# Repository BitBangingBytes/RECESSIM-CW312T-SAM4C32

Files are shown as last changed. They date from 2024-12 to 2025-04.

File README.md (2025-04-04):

Target board as seen in [RECESSIM video](https://www.youtube.com/watch?v=IOD5voFTAz8)

Note the UART Bootloader connections were routed to the wrong pins and need to be fixed. You can see the bodge wires in the video.

This does not affect the JTAG attack shown however, or programming the chip via JTAG. It works fine for that.

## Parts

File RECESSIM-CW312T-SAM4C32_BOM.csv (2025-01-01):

Reference | Value | Datasheet | Footprint | Qty | DNP | Digikey
C1,C2,C5 | 0.1uF | ~ | Capacitor_SMD:C_0603_1608Metric | 3 |  | 478-KGM15AR70J104KMCT-ND
C3,C4 | 2.2uF | ~ | Capacitor_SMD:C_0603_1608Metric | 2 |  | 1276-1886-1-ND
C6,C7,C8,C9 | 0.1uF | ~ | Capacitor_SMD:C_0603_1608Metric | 4 | DNP | 478-KGM15AR70J104KMCT-ND
R1,R2,R3,R4 | 10 | ~ | Resistor_SMD:R_0603_1608Metric | 4 |  | RR08Q10DCT-ND
R5,R6 | 100k | ~ | Resistor_SMD:R_0603_1608Metric | 2 |  | RR08P100KDCT-ND
R7 | 100 | ~ | Resistor_SMD:R_0603_1608Metric | 1 |  | RR08P100DCT-ND
U1 | ATSAM4C32C |  | RECESSIM-CW312T-SAM4C32:TQFP-100_14x14mm_P0.5mm_W0.28mm | 1 |  | 150-ATSAM4C32CA-AUT-ND

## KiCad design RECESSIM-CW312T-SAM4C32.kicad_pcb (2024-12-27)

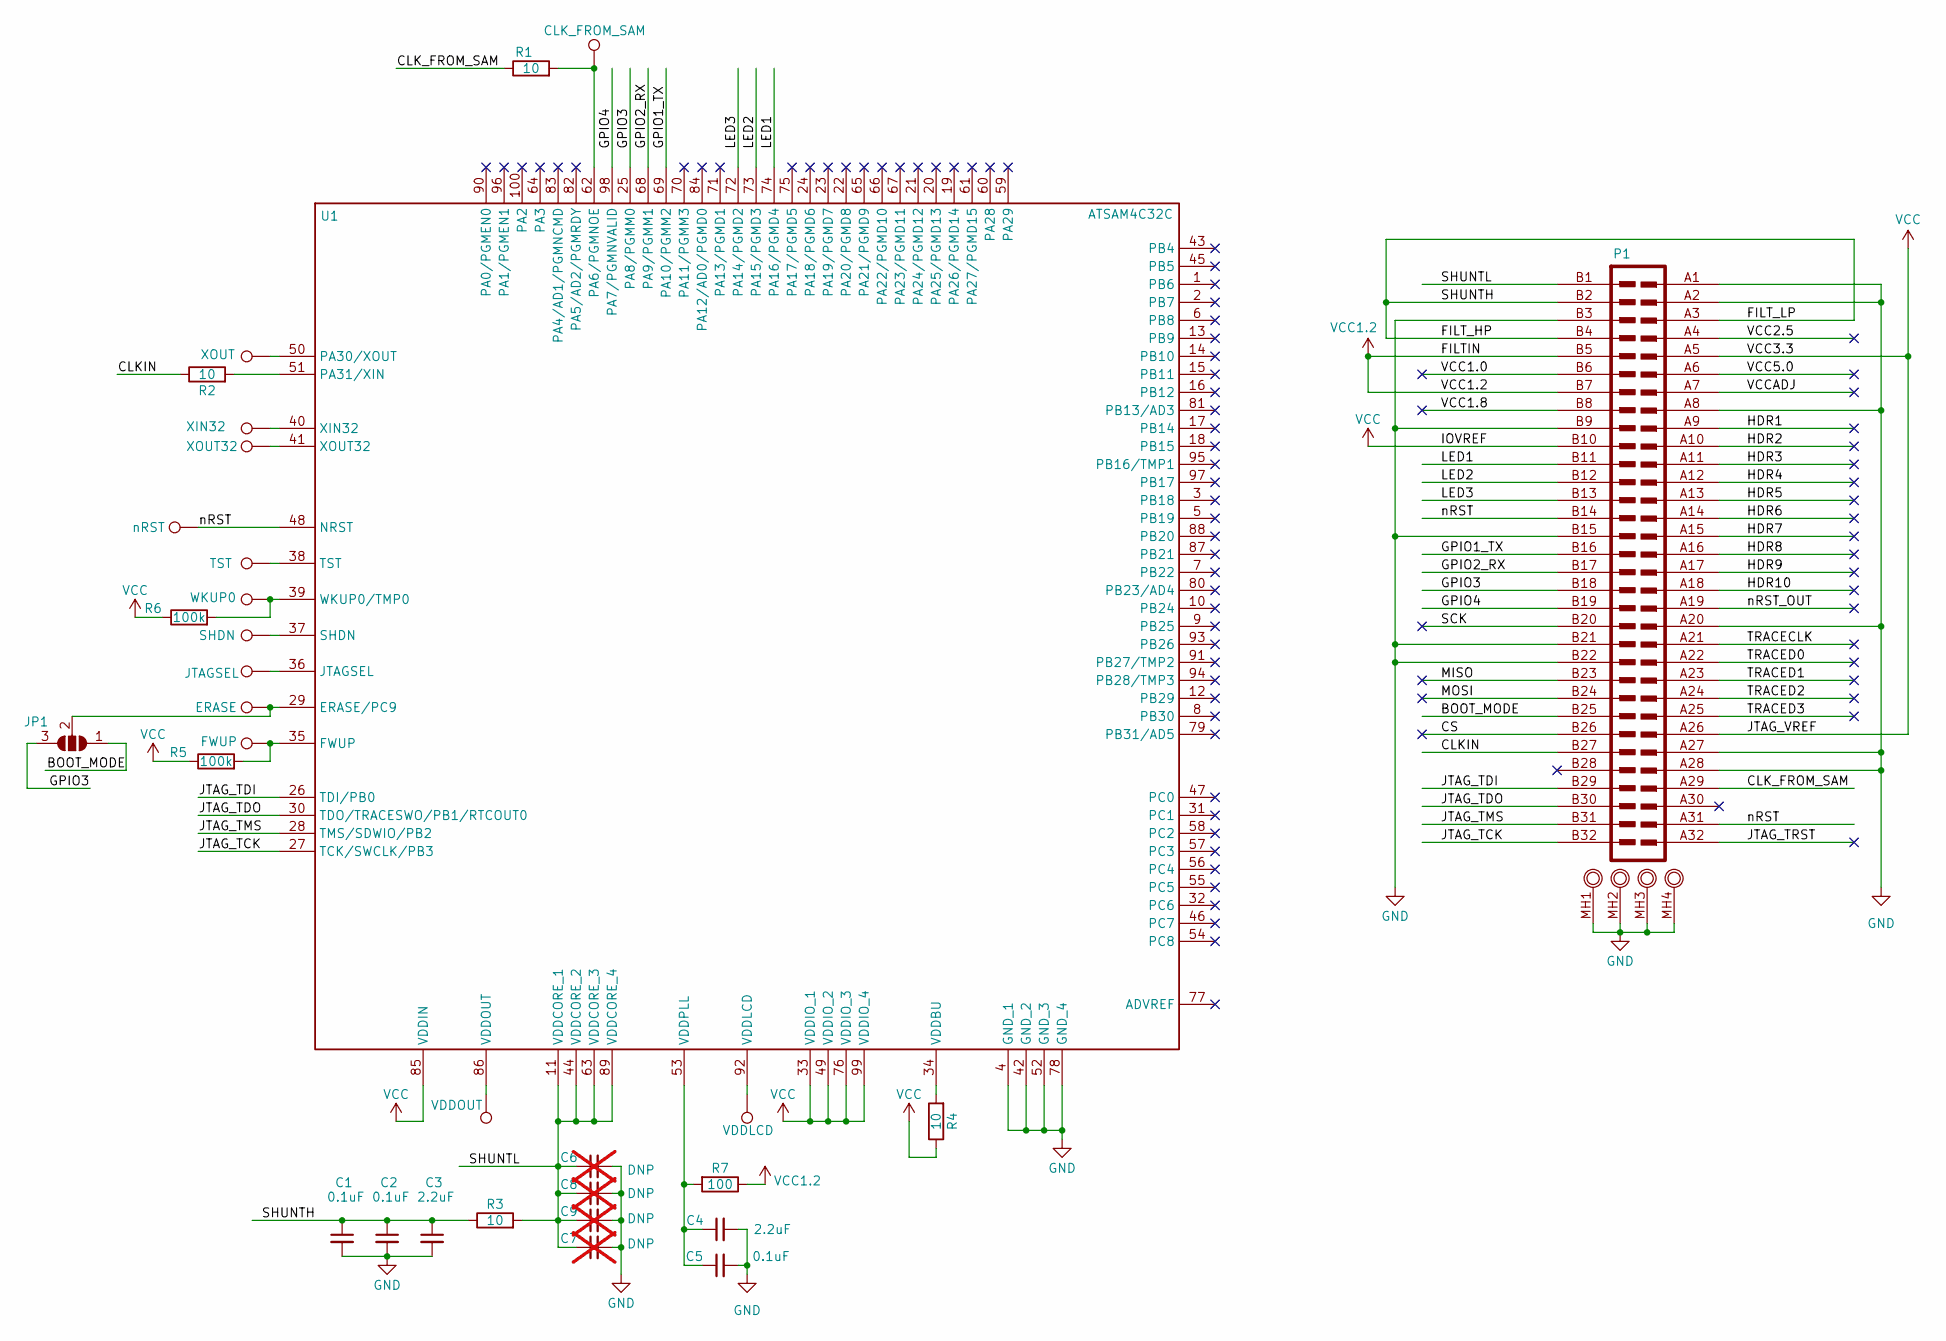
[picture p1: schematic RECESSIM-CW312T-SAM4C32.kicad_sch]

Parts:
C1, C2, C5: 0.1uF; C_0603_1608Metric
C3, C4: 2.2uF; C_0603_1608Metric
C6, C7, C8, C9: DNP; C_0603_1608Metric; not fitted
JP1: SolderJumper_3_Open; SolderJumper-3_P1.3mm_Open_RoundedPad1.0x1.5mm
P1: CW312_CardEdge
R1, R2, R3, R4: 10; R_0603_1608Metric
R5, R6: 100k; R_0603_1608Metric
R7: 100; R_0603_1608Metric
TP5: ERASE; TestPoint_Pad_1.0x1.0mm
TP6: FWUP; TestPoint_Pad_1.0x1.0mm
TP7: JTAGSEL; TestPoint_Pad_1.0x1.0mm
TP8: SHDN; TestPoint_Pad_1.0x1.0mm
TP9: VDDLCD; TestPoint_Pad_1.0x1.0mm
TP10: TST; TestPoint_Pad_1.0x1.0mm
TP11: VDDOUT; TestPoint_Pad_1.0x1.0mm
TP12: WKUP0; TestPoint_Pad_1.0x1.0mm
TP13: XIN32; TestPoint_Pad_1.0x1.0mm
TP14: XOUT32; TestPoint_Pad_1.0x1.0mm
TP15: nRST; TestPoint_Pad_1.0x1.0mm
TP16: XOUT; TestPoint_Pad_1.0x1.0mm
TP22: CLK_FROM_SAM; TestPoint_Pad_1.0x1.0mm
U1: ATSAM4C32C; TQFP-100_14x14mm_P0.5mm_W0.28mm

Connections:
/BOOT_MODE: JP1.1 (A), P1.B25
/CLKIN: P1.B27, R2.1
/CLK_FROM_SAM: P1.A29, R1.1
/CS: P1.B26
/FILT_HP: C1.1, C2.1, C3.1, P1.A3, P1.B2, P1.B4, R3.1
/GPIO1_TX: P1.B16, U1.69 (PA10/PGMM2)
/GPIO2_RX: P1.B17, U1.68 (PA9/PGMM1)
/GPIO3: JP1.3 (B), P1.B18, U1.25 (PA8/PGMM0)
/GPIO4: P1.B19, U1.98 (PA7/PGMNVALID)
/HDR1: P1.A9
/HDR2: P1.A10
/HDR3: P1.A11
/HDR4: P1.A12
/HDR5: P1.A13
/HDR6: P1.A14
/HDR7: P1.A15
/HDR8: P1.A16
/HDR9: P1.A17
/HDR10: P1.A18
/JTAG_TCK: P1.B32, U1.27 (TCK/SWCLK/PB3)
/JTAG_TDI: P1.B29, U1.26 (TDI/PB0)
/JTAG_TDO: P1.B30, U1.30 (TDO/TRACESWO/PB1/RTCOUT0)
/JTAG_TMS: P1.B31, U1.28 (TMS/SDWIO/PB2)
/JTAG_TRST: P1.A32
/LED1: P1.B11, U1.74 (PA16/PGMD4)
/LED2: P1.B12, U1.73 (PA15/PGMD3)
/LED3: P1.B13, U1.72 (PA14/PGMD2)
/MISO: P1.B23
/MOSI: P1.B24
/SCK: P1.B20
/SHUNTL: C6.1, C7.1, C8.1, C9.1, P1.B1, R3.2, U1.11 (VDDCORE_1), U1.44 (VDDCORE_2), U1.63 (VDDCORE_3), U1.89 (VDDCORE_4)
/TRACECLK: P1.A21
/TRACED0: P1.A22
/TRACED1: P1.A23
/TRACED2: P1.A24
/TRACED3: P1.A25
/VCC1.0: P1.B6
/VCC1.8: P1.B8
/VCC2.5: P1.A4
/VCC5.0: P1.A6
/VCCADJ: P1.A7
/nRST: P1.A31, P1.B14, TP15.1, U1.48 (NRST)
/nRST_OUT: P1.A19
GND: C1.2, C2.2, C3.2, C4.2, C5.2, C6.2, C7.2, C8.2, C9.2, P1.A1, P1.A2, P1.A8, P1.A20, P1.A27, P1.A28, P1.B3, P1.B9, P1.B15, P1.B21, P1.B22, P1.MH1 (MH), P1.MH2 (MH), P1.MH3 (MH), P1.MH4 (MH), U1.4 (GND_1), U1.42 (GND_2), U1.52 (GND_3), U1.78 (GND_4)
unnamed: JP1.2 (C), TP5.1, U1.29 (ERASE/PC9)
unnamed: R5.2, TP6.1, U1.35 (FWUP)
unnamed: TP7.1, U1.36 (JTAGSEL)
unnamed: R1.2, TP22.1, U1.62 (PA6/PGMNOE)
unnamed: TP16.1, U1.50 (PA30/XOUT)
unnamed: R2.2, U1.51 (PA31/XIN)
unnamed: TP8.1, U1.37 (SHDN)
unnamed: TP10.1, U1.38 (TST)
unnamed: R4.2, U1.34 (VDDBU)
unnamed: TP9.1, U1.92 (VDDLCD)
unnamed: TP11.1, U1.86 (VDDOUT)
unnamed: C4.1, C5.1, R7.2, U1.53 (VDDPLL)
unnamed: R6.2, TP12.1, U1.39 (WKUP0/TMP0)
unnamed: TP13.1, U1.40 (XIN32)
unnamed: TP14.1, U1.41 (XOUT32)
VCC: P1.A5, P1.A26, P1.B10, R4.1, R5.1, R6.1, U1.33 (VDDIO_1), U1.49 (VDDIO_2), U1.76 (VDDIO_3), U1.85 (VDDIN), U1.99 (VDDIO_4)
VCC1.2: P1.B5, P1.B7, R7.1

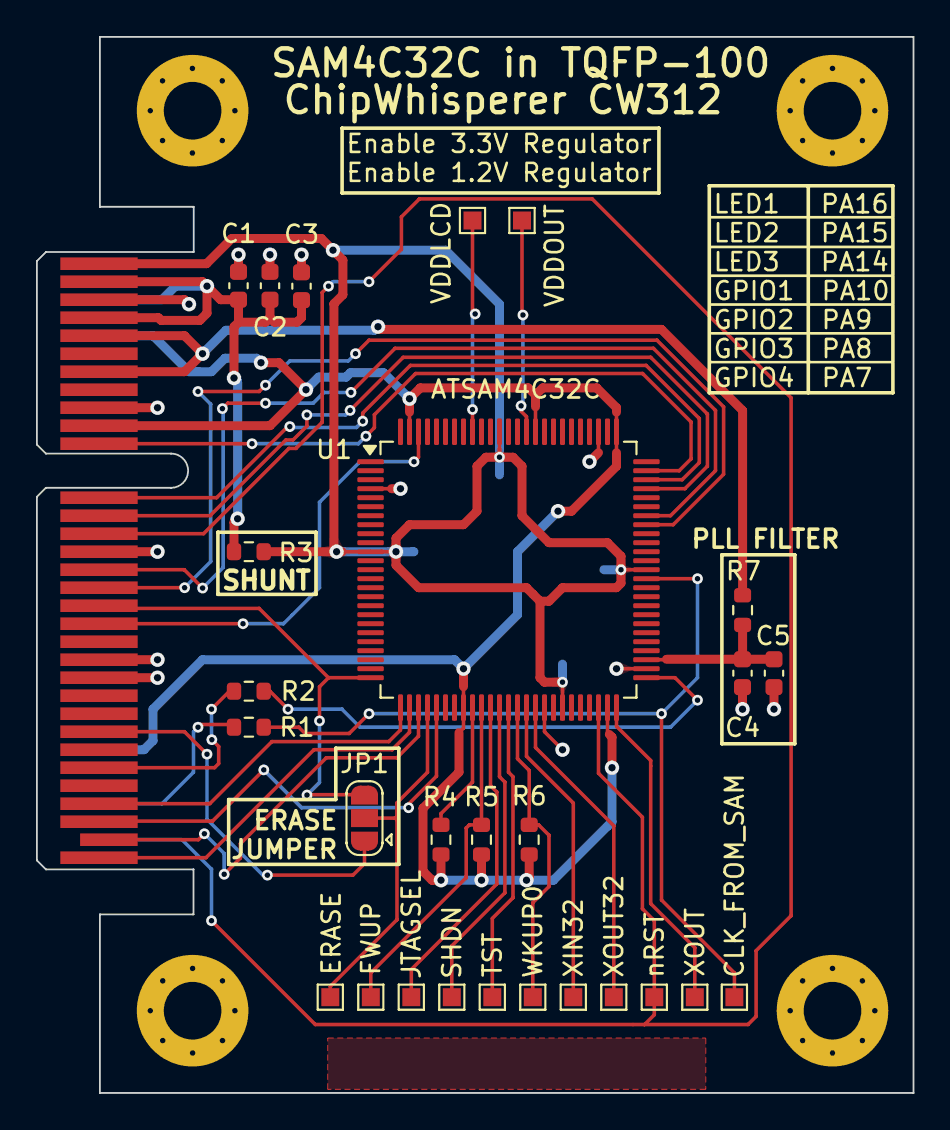
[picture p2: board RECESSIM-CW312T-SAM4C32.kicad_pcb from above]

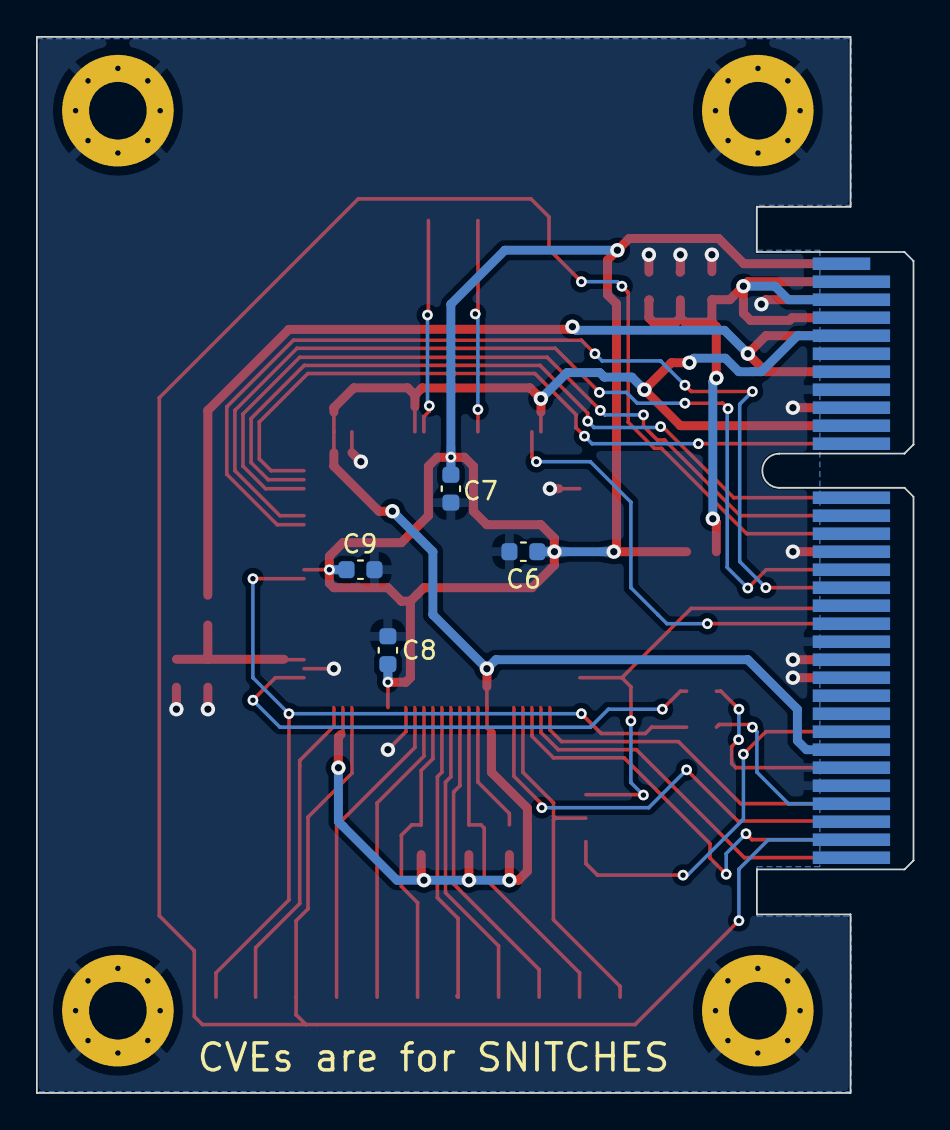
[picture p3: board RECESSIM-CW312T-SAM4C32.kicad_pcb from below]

Board: 2 copper layers, 48.7 x 58.7 mm, 32 parts (4 on the bottom side), 35 nets.

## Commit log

2024-12-16 Added test points, power and JTAG connections
    [RECESSIM-CW312T-SAM4C32.kicad_sch]
2024-12-16 Connected VDDBU to power, added more test points
    [RECESSIM-CW312T-SAM4C32.kicad_sch]
2024-12-16 Added more test points
    [RECESSIM-CW312T-SAM4C32.kicad_sch]
2024-12-16 Added CW312T card edge footprint, finalized schematic before annotating
    [RECESSIM-CW312T-SAM4C32.kicad_sch]
2024-12-16 Updated schematic footprint, annotated and ran DRC
    [RECESSIM-CW312T-SAM4C32.kicad_sch]
2024-12-16 Updated footprints for card edge and initial placement of components on board
    [RECESSIM-CW312T-SAM4C32.kicad_pcb, RECESSIM-CW312T-SAM4C32.kicad_sch]
2024-12-17 Added two necessary resistors and removed one unnecessary one
    [RECESSIM-CW312T-SAM4C32.kicad_pcb, RECESSIM-CW312T-SAM4C32.kicad_sch]
2024-12-25 Finalized PCB design, generated gerbers for version 1
    [RECESSIM-CW312T-SAM4C32-B_Cu.gbr, RECESSIM-CW312T-SAM4C32-B_Mask.gbr, RECESSIM-CW312T-SAM4C32-B_Paste.gbr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]
2024-12-27 Finalized Rev1 of the PCB design, removed unused Test Points from Schematic
    [RECESSIM-CW312T-SAM4C32-B_Cu.gbr, RECESSIM-CW312T-SAM4C32-B_Mask.gbr, RECESSIM-CW312T-SAM4C32-B_Paste.gbr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]
2024-12-27 Changed processor footprint to have pad spacing of 0.22mm so black solder mask will bridge.
    [RECESSIM-CW312T-SAM4C32-B_Cu.gbr, RECESSIM-CW312T-SAM4C32-B_Mask.gbr, RECESSIM-CW312T-SAM4C32-B_Paste.gbr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]
2025-01-01 Created BOM and added Digikey P/N's
    [RECESSIM-CW312T-SAM4C32_BOM.csv]
